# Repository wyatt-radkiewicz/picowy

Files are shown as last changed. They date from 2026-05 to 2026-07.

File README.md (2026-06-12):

# picowy Design Document
This is the design document for the picowy. This is made to be a thin, low power tomagachi like
device for my girlfriend. This design document goes over the basic system configuration and power
requirements. It enumerates every major system component. It does not go into detail about the
coding architecture, that can be found in the firmware directory.

> *eklipsed, rev. 1.0.1*

## Table of Contents
1. [Accelerometer](#accelerometer)
2. [OLED Display](#oled-display)
3. [Microcontroller](#microcontroller)
4. [Touch Panel](#touch-panel)
5. [FTDI Firmware Flasher](#ftdi-firmware-flasher)
6. [Power System](#power-system)
7. [Chassis](#chassis)

## Accelerometer
> Ultra Low-Power 3 Axis Accelerometer
- Manufacturer - *STMicroelectronics*
- Part Number - *LIS2HH12TR*
- Datasheet - [LIS2HH12](hardware/datasheets/accel/lis2hh12.pdf)
- Application Notes - [AN4662](hardware/datasheets/accel/an4662.pdf)

This accelerometer provides real world physics feedback to the simulation.
The SPI interface is used to poll acceleration data per tick of the simulation.
This uses the **Block Data Update (BDU)** feature of the LIS2HH12 to poll
data from the OUT_(X, Y, Z)_(H, L) registers while having old data be overwritten
([AN4662 Section 3.1.3](hardware/datasheets/accel/an4662.pdf#page=14)). Only the newest
data is needed, samples can be skipped since no filtering on the MCU is used.

### Parameters
- $FS=\pm4.0g$ - Measurement range in *g*
([LIS2HH12 Table 3](hardware/datasheets/accel/lis2hh12.pdf#page=10)).
- $So=0.122\frac{mg}{lsb}$ - Sensitivity in OUT registers
([LIS2HH12 Table 3](hardware/datasheets/accel/lis2hh12.pdf#page=10)).
- $ODR=50\mathrm{Hz}$ - Output data rate.
- $I_{ddA}=110\mu\mathrm{A}$ - Current consumption
([LIS2HH12 Table 4](hardware/datasheets/accel/lis2hh12.pdf#page=11)).
- $PX_G=So\times\frac{9800 mm}{s^2 \times lsb}\times\frac{128 px}{20.14 mm}
\times\frac{s}{30 ticks}=253.3\frac{px}{tick^2 \times lsb}$ -
ODR LSB to px per tick^2 conversion rate (@ 30Hz simulation rate).
  - 20.14mm - Screen size
  ([ER-OLED1.12-2 Outline Drawing](hardware/datasheets/oled/er-oled1.12-2.pdf#page=6)).

### Physics Integration
Projecting the accelerometer data onto the screen's X-Y plane is as simple as only converting
the ODR_X_HL and ODR_Y_HL registers into the screen's units and ignoring ODR_Z_HL. Multiply
ODR_X_HL and ODR_Y_HL by $PX_G$ to get the acceleration values used in the physics simulation.

Pictured below is the physical configuration of the accelerometer, where 1 is the first pin.
```
                 ^ z
                 |
               _-|-_
            _-" 1|  "-_
         _-"     |     "-_
       +-_     _-'-_     _-+
       |  "-_-"     "-_-"  |
       +-_-" "-_   _-" "-_-+
      _-" "-_   "+"   _-" "-_
  y <"       "-_ | _-"       "> x
                "+"
```
([LIS2HH12 Section 1.2](hardware/datasheets/accel/lis2hh12.pdf#page=8))

## OLED Display
> 1.12" 128x128 Monochrome White OLED Display
- Manufacturer - *EastRising*
- Part Number - *ER-OLED1.12-2W*
- Datasheet - [ER-OLED1.12-2](hardware/datasheets/oled/er-oled1.12-2.pdf)
- Reference Implementation -
[er-oled1.12-2-interfacing](hardware/datasheets/oled/er-oled1.12-2-interfacing.pdf)
- Controller - [SH1107](hardware/datasheets/oled/sh1107.pdf)
- Connector Datasheet - [ZIF20PIN](hardware/datasheets/oled/er-con20ht-1.pdf)

This OLED has a SPI interface, which can be shared with the internal measurement unit.
The 4-Wire SPI interface is selected, where A0 represents the Data/Command bit. The way that
EastRising designed the display module means that the 12V rail msut be supplied externally.

### Parameters
- $f_{SCK} = \frac{PCLK}{2} = 1.05\mathrm{MHz}$ - SPI interface speed
  - The maximum speed on the OLED's SPI interface is around 4Mhz
  ([SH1107 AC Characteristics](hardware/datasheets/oled/sh1107.pdf#page=52)).
  - The STM32 peripheral (PCLK) clock is the bottleneck. The maximum
  SPI interface speed can be set to $\frac{PCLK}{2}$
  ([RM0377 Section 26.7.1](hardware/datasheets/stm32/rm0377.pdf#page=808)).
- $IPP + IREF = 48\mu \mathrm{A}$ - Current from 12V Rail
([ER-OLED1.12-2 Section 4.3](hardware/datasheets/oled/er-oled1.12-2.pdf#page=9))
- $IDD = 100\mu \mathrm{A}$ - Current from 3.3V Rail
([ER-OLED1.12-2 Section 4.3](hardware/datasheets/oled/er-oled1.12-2.pdf#page=9))

## Microcontroller
> Arm Cortex M0+ Microcontroller 16KB Flash 2KB RAM
- Manufacturer - *STMicroelectronics*
- Part Number - *STM32L011G4U6TR*
- Datasheet - [STM32L011](hardware/datasheets/stm32/stm32l011.pdf)
- Reference Manual - [RM0377](hardware/datasheets/stm32/rm0377.pdf)
- Bootloader Manual - [AN2606](hardware/datasheets/stm32/an2606.pdf)
- USART Bootloader Protocol Manual - [AN3155](hardware/datasheets/stm32/an3155.pdf)
- Programmer's Manual - [PM0223](hardware/datasheets/stm32/pm0223.pdf)

The main program will be a state machine where it runs all functions and then sleeps. This repeats
on a main $30\mathrm{Hz}$ timer.

### Power Mode and Clock Setup
- **Power Mode (VCORE)** - To save power *VCORE Range 3 (1.2V)* will be selected
[RM0377 Section 6.1.4](hardware/datasheets/stm32/rm0377.pdf#page=138).
- **System Clock (SYSCLK)** - SYSCLK will run from the MSI (Multispeed Internal) clock at
$2.1\mathrm{MHz}$ [RM0377 Section 7.2.3](hardware/datasheets/stm32/rm0377.pdf#page=174).
- **Peripherial Clock (PCLK)** - PCLK will be run at the same frequency of $2.1\mathrm{MHz}$.
- **Run Mode** -  When running with no peripherials on except FLASH, and interpolating data from
[STM32L011 Table 22](hardware/datasheets/stm32/stm32l011.pdf#page=53), around $300\mu\mathrm{A}$ is
consumed while running.
- **Sleep Mode** - When in sleep mode running at $65\mathrm{kHz}$ and without FLASH, around
$26.5\mu\mathrm{A}$ is consumed
[STM32L011 Table 26](hardware/datasheets/stm32/stm32l011.pdf#page=56).

### States
#### 1. Wakeup
LPTIM1 is running at $30\mathrm{Hz}$, and wakes up the system.
Driven off of the stable LSI (Low Speed Internal) clock source so that MSI can be changed during
operation. System sets MSI clock back to $2.1\mathrm{MHz}$.
- **Required Peripherials:** PWR, FLASH, LPTIM1
- **Power Consumption:** $300\mu\mathrm{A} + 36.0\mu\mathrm{A} = 336.0\mu\mathrm{A}$
- **Average Runtime $\approx 0.266\mathrm{ms}$**
  - 8 cycles at 65kHz [STM32L011 Section 6.3.5](hardware/datasheets/stm32/stm32l011.pdf#page=62)
  - N cycles at 2.1Mhz (Somewhere in the 100-200 cycles range)

#### 2. Poll Touch Screen
First it runs the *Sense* operation to see if the touch screen is being touched, and only if there
is touch detected does it start up ADC1 and run the *X Pos* and *Y Pos* modes. ADC1 is configured
to run with 1.5 sample time and to run off of the PCLK with 12 bit resolution.
- **Required Peripherials:** PWR, FLASH, LPTIM1, ADC1, GPIO
- **Power Consumption:** $300\mu\mathrm{A} + 61.2\mu\mathrm{A} = 361.2\mu\mathrm{A}$
- **Average Runtime $\approx 0.122\mathrm{ms}$**
  - $1\mu\mathrm{s}$ ADC Power up Time
  [STM32L011 Table 54](hardware/datasheets/stm32/stm32l011.pdf#page=81)
  - $2\times\left(12.5 + 1.5\right)\times\frac{1}{1.05\mathrm{Mhz}}=27\mu\mathrm{s}$
  2 ADC Sample Times [STM32L011 Table 54](hardware/datasheets/stm32/stm32l011.pdf#page=81)
  - N cycles at 2.1Mhz (Somewhere in the 100-200 cycles range)

#### 3. Poll Accelerometer
SPI1 should use $CPOL=1, CPHA=1$ when communicating with the accelerometer. ODR_(X, Y, Z)_(H, L) is
read and converted into *px/tick^2* using the accelerometer's communitcation protocol
[LIS2HH12 Section 6.2](hardware/datasheets/accel/lis2hh12.pdf#page=25). With this protocol,
the ODR_X_L register can be read, and then the rest can follow with DMA1 clocking the SCK signal
for the rest.
- **Required Peripherials:** PWR, FLASH, LPTIM1, SPI1, DMA1, GPIO
- **Power Consumption:** $300\mu\mathrm{A} + 68.6\mu\mathrm{A} = 368.6\mu\mathrm{A}$
- **Average Runtime $\approx 0.291\mathrm{ms}$**
  - 56 SPI cycles
  - N cycles at 2.1Mhz (500 cycles range)

#### 4. Update Simulation
The simulation will use a state machine for the character, and the character will be affected by
the external acceleration seen by the accelerometer, and the touch sensor. It will update the
internal screen bitmap for the next step.
- **Required Peripherials:** PWR, FLASH, LPTIM1
- **Power Consumption:** $300\mu\mathrm{A} + 36.0\mu\mathrm{A} = 336.0\mu\mathrm{A}$
- **Average Runtime $\approx 4.76\mathrm{ms}$**
  - N cycles at 2.1Mhz (10,000 cycles budget)

#### 5. Update Screen
Since the 128x128 screen is too large to fit into 2KB RAM, work arounds are needed. A sprite based
approach with X, Y, W, H pairs and a reference to the bitmap in FLASH works, and with a system that
knows where sprites were previously, full screen rewrites are not needed. Even if a full screen
refresh was needed, it would only take under $18\mathrm{ms}$ when SPI1 runs at full speed
($1.05\mathrm{MHz}$).
- **Required Peripherials:** PWR, FLASH, LPTIM1, SPI1, DMA1, GPIO
- **Power Consumption:** $300\mu\mathrm{A} + 60.3\mu\mathrm{A} = 360.3\mu\mathrm{A}$
- **Average Runtime $\approx 6.19\mathrm{ms}$**
  - 4000 SPI1 cycles (Assuming 1/4 of screen is refreshed)
  - N cycles at 2.1Mhz (5,000 cycles budget)

#### 6. Sleep
This sets the MSI clock to $65\mathrm{kHz}$, disables relevant clock
blocks and peripherals, and exits the LPTIM1 interrupt to go back into sleep mode.
- **Required Peripherials:** PWR, FLASH, LPTIM1
- **Power Consumption:** $26.5\mu\mathrm{A} + 36.0\mu\mathrm{A} = 62.5\mu\mathrm{A}$

### Average Power Consumption
- Time in *Run* mode: $11.7\mathrm{ms}$
- Average current: $360\mu\mathrm{A}\times\frac{11.7}{33.33}+70\mu\mathrm{A}\times
\frac{21.63}{33.33}\approx172\mu\mathrm{A}$

### Debug Connector
> Tag Connect 2030 Solderless Connection
- Manufacturer - *Tag-Connect*
- Part Number - *TC2030*
- Datasheet - [TC2030](hardware/datasheets/conn/tc2030.pdf)

The TC2030 will be connected the STM32's SWCLK, SWDIO, 3.3V, GND, NRST. NRST will be pulled up to
$V_{DD}$. This will use the Serial Wire Debug (SWD) protocol.

## Touch Panel
> 1.44" 4 Wire Resistive Touch Screen
- Manufacturer - *EastRising*
- Part Number - *ER-TP1.44-1*
- Datasheet - [ER-TP1.44-1](hardware/datasheets/touch/er-tp1.44-1.pdf)

The datasheet doesn't contain any info on axis resistance. Design is made around that limitation,
but still the minimum and maximum allowed for the design will be selected for
$300\Omega-600\Omega$. The touch panel circuitry uses no current if the panel is not being touched.

### Diagram
- $R_{AX}$ is the axis resistance, anywhere between the minimum and maximum.
- $R_{TP}$ is current limiting resistor $R_{TP}$.
- *XL*, *YU*, *XR*, *YD* are connected to the STM32's GPIO pins.
```
   Inside TP    . To GPIO
                .
  +--------------------- XL
  |             .
  |      +-------------- YU
  |      |      .
  |     R_AX    .
  |      |      .
  +-R_AX-?-R_AX---R_TP-- XR
         |      .
        R_AX    .
         |      .
         +--------R_TP-- YD
                .
```

### Parameters
- $R_{PD} >= 25k\Omega$ - Minimum pulldown resistor value
([STM32L011 Table 50](hardware/datasheets/stm32/stm32l011.pdf#page=75)).
- $I_{MAX}=2\mathrm{mA}$

### Operation Modes
When sleeping, the touch panel GPIO is all set to Input (*no* pullup/down). This configuration
consumes no current.

#### Touch Sense
| Pin | State |
|-----|---|
| XL  | Out Push-Pull, HI |
| XR  | HZ |
| YU  | In Pull-Down |
| YD  | HZ |
- $I_{TP}=\frac{V_{DD}}{R_{PD}}=0.132\mathrm{mA}$ - GPIO source/sink current (if pressed)
- $V_{TP}=V_{DD}\frac{R_{PD}}{2R_{AX}+R_{IA}+R_{PD}}=3.03\mathrm{V}$ - Touch sense level
  - $R_{IA}$ - Inter-axis touch resistance ($0-1000\Omega$)

#### X/Y Position Reading
| State | XL | XR | YU | YD |
|---|---|---|---|---|
| X Pos | Out Push-Pull, LO | Out Push-Pull, HI | ADC In | HZ |
| Y Pos | ADC In | HZ | Out Push-Pull, LO | Out Push-Pull, HI |

$R_{TP} = 1.4\mathrm{k}\Omega$ - What to use for $R_{TP}$ since only these modes use it
- $R_{TP} > \frac{V_{DD}}{I_{MAX}}-R_{AX}$ - What to select for $R_{TP}$ to keep current low

## FTDI Firmware Flasher
> USB to UART Bridge for Firmware Flashing
- Manufacturer - *FTDI, Future Technology Devices International Ltd*
- Part Number - *FT260Q-T*
- Datasheet - [FT260](hardware/datasheets/ftdi/ft260.pdf)
- Application Notes - [AN394](hardware/datasheets/ftdi/an394.pdf)

This will be used to boot the STM32 into the USART Boot Loader
([AN3155](hardware/datasheets/stm32/an3155.pdf)). Two GPIOs will be used on the FT260, one to
assert NRST on the STM32, and the other to assert the BOOT0 pin on the STM32 to get it into
bootloader mode [AN2606 Table 2](hardware/datasheets/stm32/an2606.pdf#page=34). For this,
nBOOT_SEL must be 0 [RM0377 Section 3.7.8](hardware/datasheets/stm32/rm0377.pdf#page=110).

Support for an external EEPROM configuration chip for the FT260 will be made by making a space
for it on the PCB (need not be populated). This EEPROM chip communicates over $\mathrm{I^2C}$
[FT260 Section 9](hardware/datasheets/ftdi/ft260.pdf#page=44).

### Parameters
- $DCNF1 = 1, DCNF0 = 0$ - Only USART interface is enabled
[FT260 Section 5.1](hardware/datasheets/ftdi/ft260.pdf#page=17)
- $PARITY = EVEN$ [AN3155 Section 3](hardware/datasheets/stm32/an3155.pdf#page=9)
- $Baud\;Rate = 115200$ [AN3155 Section 2.2](hardware/datasheets/stm32/an3155.pdf#page=7)

## Power System
There are 3 distinct power rails, VBUS, 3V3, and 12V. The devices connected to each are:
| RAIL | DEVICES | CURRENT |
|---|---|---|
| VBUS | FT260 | $9.6\mathrm{mA}$ [FT260 Table Section 6.3](hardware/datasheets/ftdi/ft260.pdf#page=29) |
| | Battery Charger | $50\mathrm{mA}$ Set by $EN1=HI,EN2=LO$ [BQ24230 Section 7.5](hardware/datasheets/charger/bq24230.pdf#page=9)  |
| 3V3  | STM32 | $172\mu\mathrm{A}$ [STM32 Average Power Consumption](#microcontroller) |
| | OLED | $100\mu\mathrm{A}$ [OLED Display 3V3 Current](#oled-display) |
| | Accelerometer | $110\mu\mathrm{A}$ [Accelerometer Current](#accelerometer) |
| 12V  | OLED Driver | $32\mu\mathrm{A}$ [OLED Display Driver 12V Current](#oled-display) |

The rated battery charging rate and lack of circuitry needed to negociate USB Battery Charging or
Power Delivery means that the battery charger will have an input current limit of $50\mathrm{mA}$.

With the selected parts, the 3V3 rail draws $1.4\mathrm{mW}$ because of the LDO. The 12V rail draws
$1.2\mathrm{mW}$ due to the $\approx50\%$ efficiency. This means the battery will be sourcing
around $0.7\mathrm{mA}$.

### Battery <TODO>
> 3.7V Thin Lithium Ion Battery Rechargeable
- Manufacturer - *GlobTek, Inc.*
- Part Number - *BL0105F2635161S1PCAT*
- Datasheet - [BL0105F2635161S1PCAT](hardware/datasheets/battery/battery.pdf)

Is very thin $2.8\mathrm{mm}$ thick battery, with thin connector. Stay in the $50\mathrm{mA}$ range
for charging [BL0105F2635161S1PCAT Section 3](hardware/datasheets/battery/battery.pdf#page=3).

#### Male Connector (PCB Side)
- Manufacturer - *Hirose Electric Co Ltd*
- Part Number - *DF65-3P-1.7V(21)*
- Drawing - [DF65-3P-1.7V-21](hardware/datasheets/conn/df65-3p-1.7v-21.pdf)

### Battery Charger
> Battery Charger and Power Path Managment
- Manufacturer - *Texas Instruments*
- Part Number - *BQ24230RGTR*
- Datasheet - [BQ24230](hardware/datasheets/charger/bq24230.pdf)

Using this power path battery charger, it allows instant on from a dead battery. Use custom current
limit though external resistor to give some room for the FT260 to also source current on VBUS and
to not charge the battery at its max all the time.

### Fuel Gauge
> System Side Impeadance Track Fuel Gauge
- Manufacturer - *Texas Instruments*
- Part Number - *BQ27441DRZT-G1A*
- Datasheet - [BQ27441-G1](hardware/datasheets/gauge/bq27441-g1.pdf)
- Technical Reference - [SLUUAC9A](hardware/datasheets/gauge/sluuac9a.pdf)

This is an optional component, and can be added to the $\mathrm{I^2C}$ bus on the STM32 to measure
how much battery is left and how much current the system consumes.

### 3V3 Rail
> Low Noise LDO Voltage Regulator
- Manufacturer - *Texas Instruments*
- Part Number - *TPS7A2033PDBVR*
- Datasheet - [TPS7A20](hardware/datasheets/ldo/tps7a20.pdf)

As shown the in part number, *TPS7A20***33***PDBVR* is a 3.3V low noise, low $I_Q$ LDO for
the 3.3V rail.

### 12V Rail
> Power Step-Up DC-DC Converter
- Manufacturer - *Texas Intruments*
- Part Number - *TPS61040DDCR*
- Datasheet - [TPS61040](hardware/datasheets/boost/tps61040.pdf)

The boost converter suggested by the reference implementation for the OLED. Will have around a
70% efficency a the OLED's advertised current.

## Chassis
### Front View
#### Diagram
```
          __= = = = = = = = = = = = = = =+
       _-"''"-_                          |
     ."        ".                        |
    /   +----+= =\= = = = = = = = =+     |
   /  +--------+= \ = = = = =+     |     |
  ,|  |+------+|= |.= =+     |     |     |
  /   |||    |||   \   |DISP |TPNL |BATT |A
  |   |||    |||   |   |     |     |     |
  \   |+------+|= =/= =+     |     |     |
   \  +--------+= / = = = = =+     |     |
  | "-_ +----+=_-"=|= = = = = = = =+     |
      '"-____-"'= = = = = = = = = = = = =+
  |                |
                    
  |                |
  +----------------+
          B
```
#### Dimensions
| PART | DIMENSION | DESCRIPTION | SIZE (mm) |
|---|---|---|---|
| | A | Device Height | 70 |
| | B | Device Width | 60 |
| DISP [ER-OLED1.12-2 Section 3.1](hardware/datasheets/oled/er-oled1.12-2.pdf#page=6) | H | Display Height | 30.3 |
| | W | Display Width | 27.2 |
| | C | FPC Connector Length (min) | 19.15 |
| TPNL [ER-TP1.44-1](hardware/datasheets/touch/er-tp1.44-1.pdf) | H | Touch Panel Height (max) | 30.7 |
| | W | Touch Panel Width (max) | 34.9 |
| | C | FPC Connector Length (min) | 9.2 |
| BATT [BL0105F2635161S1PCAT Section 8](hardware/datasheets/battery/battery.pdf#page=4) | H | Battery Height (max) | 37 |
| | W | Battery Width (max) | 16.5 |

### Side View
#### Diagram
```
  ________.              .________      
  __A_____|______________|________   }A
  __B___|         C         |_____ = }B= = = =]= = = = =]
        +-+---------------+-+= = = = = = = = =]C        ]H
    H     |_______D_______|          }D                 ]
  _________|      F      |________ = = = = = =]= = = = =]
  __E______|_____________|________ = }E= = = =]F
  __G_____________________________   }G
```

#### Dimensions
| DIMENSION | DESCRIPTION | SIZE (mm) |
|---|---|---|
| A | Acrylic Sheet Thickness (max) | 1.1 |
| B | Acrylic Sheet Thickness (max) | 1.1 |
| C [ER-TP1.44-1](hardware/datasheets/touch/er-tp1.44-1.pdf) | Touch Panel Thickness (max) | 1.2 ($1.1\pm0.1$) |
| D [ER-OLED1.12-2 Section 3.1](hardware/datasheets/oled/er-oled1.12-2.pdf#page=6) | OLED Display Thickness (max) | 1.35 ($1.25\pm0.1$) |
| E | PCB Thickness (max) | 1.7 |
| F  [BL0105F2635161S1PCAT Section 8](hardware/datasheets/battery/battery.pdf#page=4)| Battery Thickness (max) | 2.8 |
| G | Acrylic Sheet Thickness (max) | 1.1 |

- **Full Thickness**
  - $nom = 8\mathrm{mm}$
  - $min = 7.55\mathrm{mm}$
- **PCB Acrylic Clearance** $= 2.5\pm0.35\mathrm{mm}$
- **PCB Touch Panel Clearance** $= 2.45\pm0.2\mathrm{mm}$
- **PCB OLED Clearance** $= 1.2\pm0.1\mathrm{mm}$

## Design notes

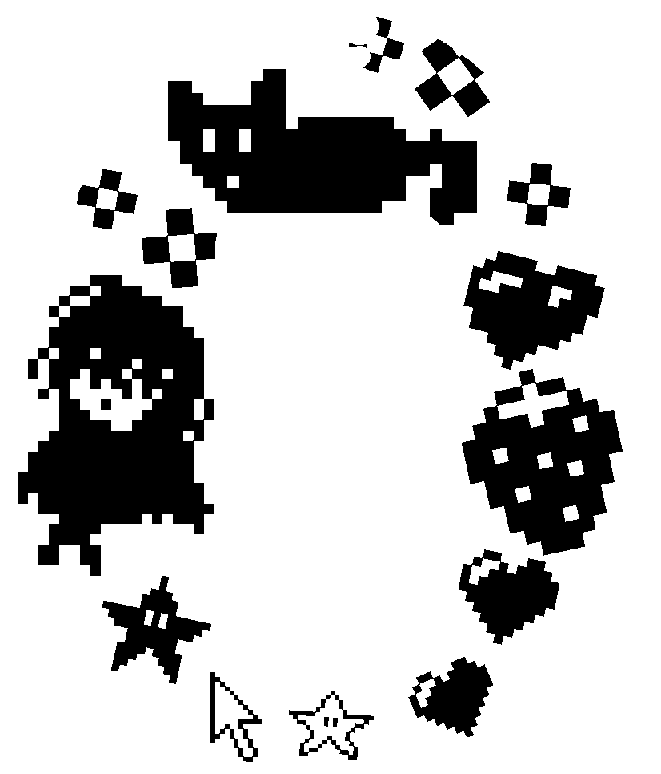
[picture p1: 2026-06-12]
hardware/images/silkscreen-back.png

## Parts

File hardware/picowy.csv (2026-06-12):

Reference | Qty | Value | Manufacturer PN | Manufacturer
BT1 | 1 | Battery | BL0105F2635161S1PCAT | 261635 3.7 V Lithium-Ion Battery Rechargeable (Secondary) 105mAh
C1,C5,C6,C11,C12,C13,C18,C19,C20,C23 | 10 | 100n | C0603C104K3RACTU | KEMET
C2,C3 | 2 | 47p | GCM1885C2A470JA16D | Murata Electronics
C4,C21,C31 | 3 | 10u | GRM188R60J106ME47D | Murata Electronics
C7,C8,C9,C14,C15,C17,C30,C32,C34 | 9 | 4.7u | GRT188C81E475KE13D | Murata Electronics
C10,C16,C22,C25,C26,C27,C28,C29 | 8 | 1u | C0603C105K4RACTU | KEMET
C24 | 1 | 0.47u | GRM188R71E474KA12D | Murata Electronics
C33 | 1 | 4.7p | CC0603CRNPO9BN4R7 | YAGEO
D1 | 1 | STPS0530Z | STPS0530Z | STMicroelectronics
F1 | 1 | VBUS Polyfuse | 0ZCJ0025AF2E | Bel Fuse Inc.
J2 | 1 | Battery Connector | DF65-3P-1.7V(21) | Hirose Electric Co Ltd
J3 | 1 | USB_C_Receptacle_USB2.0_14P | 2130830005 | Molex
L1 | 1 | 6.8u | B82422H1682K000 | TDK
Q1 | 1 | PMOS | BSS84-7-F | Diodes Incorporated
R1,R17,R18 | 3 | 5.1k | RC0603FR-075K1L | YAGEO
R2,R3 | 2 | 1.4k | AC0603FR-071K4L | YAGEO
R4,R5 | 2 | 33 | RC0603FR-0733RL | YAGEO
R6,R7 | 2 | 1k | RC0603FR-071KL | YAGEO
R8,R13,R14,R16,R21,R24,R25,R26 | 8 | 10k | RC0603FR-0710KL | YAGEO
R9 | 1 | 910k | RC0603FR-07910KL | YAGEO
R10 | 1 | 4.7k | RC0402JR-074K7L | YAGEO
R11,R12 | 2 | 2.2k | RC0603FR-072K2L | YAGEO
R15 | 1 | 10m | RL0816T-R010-F | Susumu
R19 | 1 | 17.4k | RT0603DRD0717K4L | YAGEO
R20 | 1 | 30k | RC0603JR-0730KL | YAGEO
R22 | 1 | 1.8M | AC0603FR-071M8L | YAGEO
R23 | 1 | 205k | RC0603FR-07205KL | YAGEO
U1 | 1 | ER-TP1.44-1 | ER-TP1.44-1 | EastRising
U2 | 1 | LIS2HH12 | LIS2HH12TR | STMicroelectronics
U3 | 1 | FT260Q | FT260S-U | FTDI, Future Technology Devices International Ltd
U4 | 1 | ER-OLED1.12-2W | ER-OLED1.12-2W | EastRising
U5 | 1 | AT24CS04-SSHM | AT24CS04-SSHM-T | Microchip Technology
U6 | 1 | STM32L011G4Ux | STM32L011G4U6TR | STMicroelectronics
U7 | 1 | USBLC6-2SC6 | USBLC6-2SC6 | STMicroelectronics
U9 | 1 | TPS7A20xxxDBV | TPS7A2033PDBVR | Texas Instruments
U10 | 1 | BQ24230RGT | BQ24230RGTT | Texas Instruments
U11 | 1 | TPS61040DDC | TPS61040DDCR | Texas Instruments
U12 | 1 | BQ27441-G1 | BQ27441DRZT-G1A | Texas Instruments

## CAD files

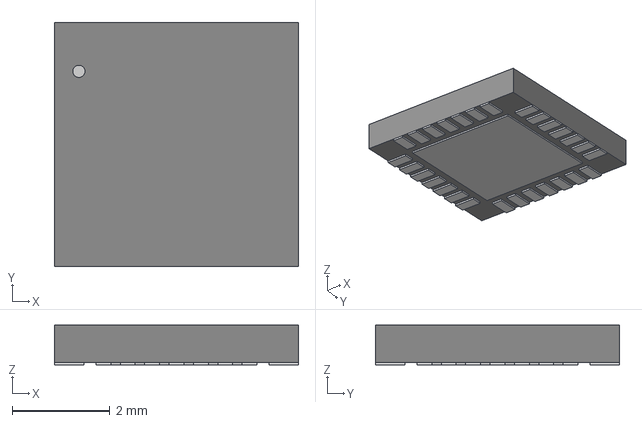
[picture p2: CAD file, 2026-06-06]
hardware/3dmodels/WQFN-28_FTD.step
5.00 x 5.00 x 0.815 mm

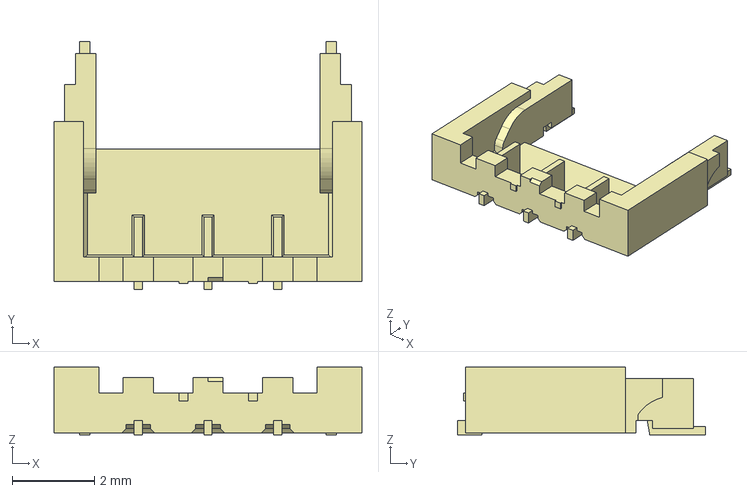
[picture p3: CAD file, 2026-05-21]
hardware/3dmodels/DF65-3P-1.7V.stp
7.50 x 6.05 x 1.65 mm

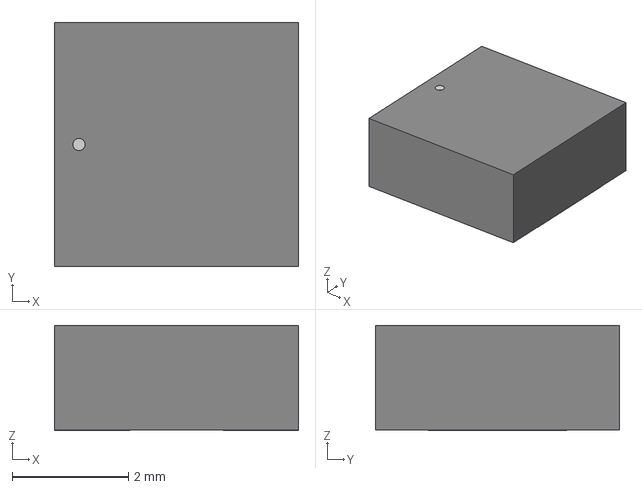
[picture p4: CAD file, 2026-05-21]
hardware/3dmodels/IND_LQH44PN_PR_MUR.step
4.19 x 4.19 x 1.81 mm

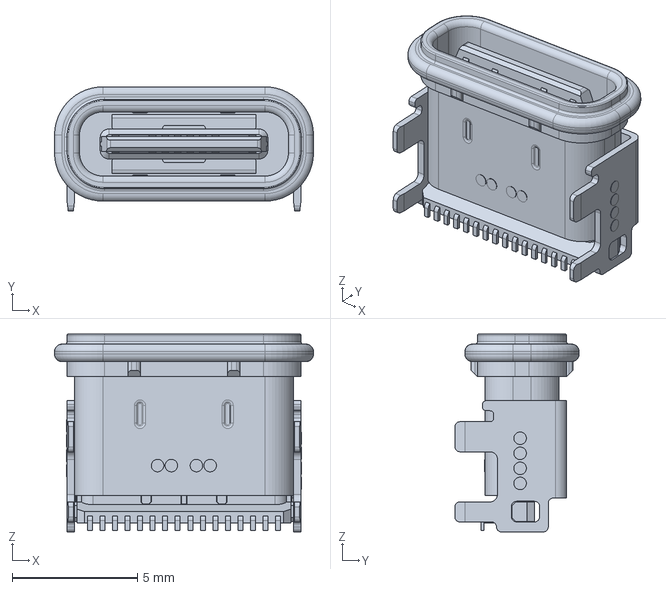
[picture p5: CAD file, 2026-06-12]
hardware/3dmodels/2130830005.stp
10.3 x 4.96 x 7.90 mm

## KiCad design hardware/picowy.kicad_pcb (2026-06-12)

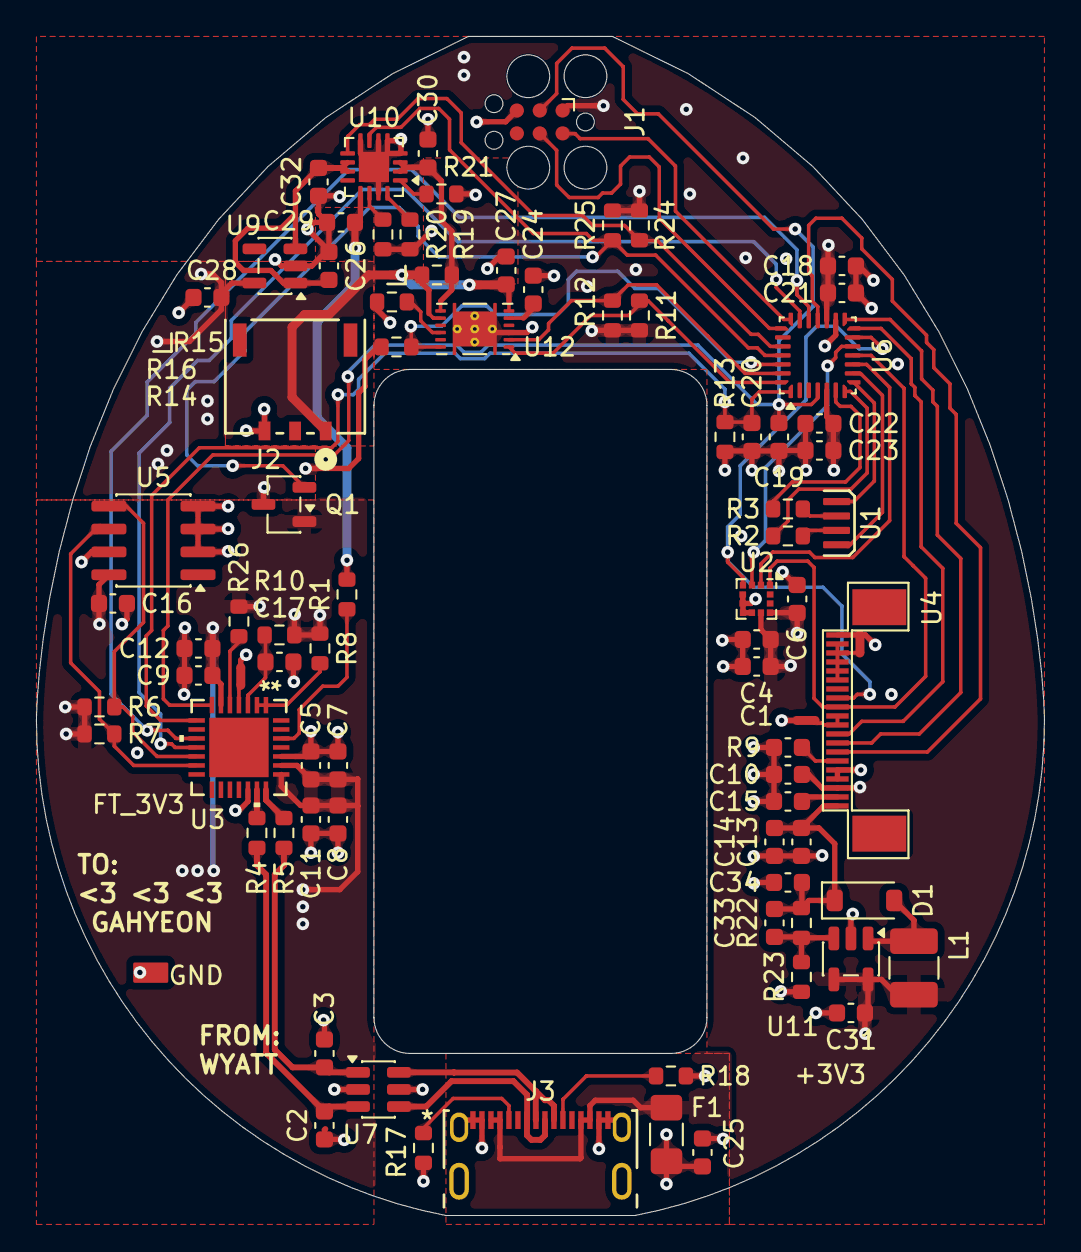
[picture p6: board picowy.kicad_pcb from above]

Board: 4 copper layers, 56.0 x 65.5 mm, 81 parts (0 on the bottom side), 59 nets.

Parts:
C1, C5, C6, C11, C12, C13, C18, C19, C20, C23: 100n; C_0603_1608Metric
C2, C3: 47p; C_0603_1608Metric
C4, C21, C31: 10u; C_0603_1608Metric
C7, C8, C9, C14, C15, C17, C30, C32, C34: 4.7u; C_0603_1608Metric
C10, C16, C22, C25, C26, C27, C28, C29: 1u; C_0603_1608Metric
C24: 0.47u; C_0603_1608Metric
C33: 4.7p; C_0603_1608Metric
D1: STPS0530Z; D_SOD-123
F1: VBUS Polyfuse; Fuse_1206_3216Metric_Pad1.42x1.75mm_HandSolder
J1: Conn_ARM_SWD_TagConnect_TC2030; Tag-Connect_TC2030-IDC-FP_2x03_P1.27mm_Vertical
J2: Battery Connector; CONN_DF65-3P-1.7V21_HIR
J3: USB_C_Receptacle_USB2.0_14P; 2130830005_MOL
L1: 6.8u; L_1210_3225Metric_Pad1.42x2.65mm_HandSolder
NT1: OLED_GPIO_NT; NetTie-2_SMD_Pad0.5mm
NT2: FT_GPIO_GND; NetTie-2_SMD_Pad0.5mm
NT3: OLED_GPIO_NT2; NetTie-2_SMD_Pad0.5mm
Q1: PMOS; SOT-23-3
R1, R17, R18: 5.1k; R_0603_1608Metric
R2, R3: 1.4k; R_0603_1608Metric
R4, R5: 33; R_0603_1608Metric
R6, R7: 1k; R_0603_1608Metric
R8, R13, R14, R16, R21, R24, R25, R26: 10k; R_0603_1608Metric
R9: 910k; C_0603_1608Metric
R10: 4.7k; R_0603_1608Metric
R11, R12: 2.2k; R_0603_1608Metric
R15: 10m; R_0603_1608Metric
R19: 17.4k; R_0603_1608Metric
R20: 30k; R_0603_1608Metric
R22: 1.8M; R_0603_1608Metric
R23: 205k; R_0603_1608Metric
U1: ER-TP1.44-1
U2: LIS2HH12; LGA-12_2x2mm_P0.5mm
U3: FT260Q; WQFN-28_FTD
U4: ER-OLED1.12-2W; ER-CON20HT-1
U5: AT24CS04-SSHM; SOIC-8_3.9x4.9mm_P1.27mm
U6: STM32L011G4Ux; QFN-28_4x4mm_P0.5mm
U7: USBLC6-2SC6; SOT-23-6
U9: TPS7A20xxxDBV; SOT-23-5
U10: BQ24230RGT; VQFN-16-1EP_3x3mm_P0.5mm_EP1.68x1.68mm
U11: TPS61040DDC; SOT-23-5
U12: BQ27441-G1; Texas_S-PDSO-N12

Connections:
+3V3: C1.1, C4.1, C6.1, C10.1, C18.1, C21.1, C22.1, C23.1, C28.1, C31.1, J1.1 (VCC), L1.1, Q1.3 (S), R11.1, R12.2, R14.1, R24.1, R25.1, U2.9 (Vdd), U2.10 (Vdd_IO), U4.3 (VDD), U6.5 (VDDA), U6.17 (VDD), U9.5 (OUT), U11.4 (EN), U11.5 (VIN)
+12V: C13.1, C14.1, C33.1, C34.1, D1.1 (K), R22.1, U4.1 (VPP)
+BATT: C27.1, J2.1, R15.2, U12.6 (BAT), U12.8 (SRP)
/Main System/FT.SCL: R7.2, U3.13 (SDA), U5.6 (SCL)
/Main System/FT.SDA: R6.2, U3.12 (SCL), U5.5 (SDA)
/Main System/FT_D+: R5.1, U3.21 (DP)
/Main System/FT_D-: R4.2, U3.20 (DM)
/Main System/FT_VBUS_DET: R1.1, U3.26 (VBUS_DET)
/Main System/IREF: R9.1, U4.6 (IREF)
/Main System/OLED_GPIO_GND: NT1.2, U4.15 (D3), U4.16 (D4), U4.17 (D5), U4.18 (D6), U4.19 (D7)
/Main System/OLED_GPIO_GND2: NT3.2, U4.10 (~WR), U4.11 (E/~RD)
/Main System/VCOMH: C15.1, U4.2 (VCOMH)
/Main System/XR_TP: R3.1, U1.3 (XR)
/Main System/YD_TP: R2.1, U1.2 (YD)
/Power System/12V_FB: C33.2, R22.2, R23.1, U11.3 (FB)
/Power System/12V_SW: D1.2 (A), L1.2, U11.1 (SW)
/Power System/CHG_ISET: R19.2, U10.16 (ISET)
/Power System/CHG_TMR: R20.2, U10.14 (TMR)
/Power System/CHG_TS: R21.1, U10.1 (TS)
/Power System/GAUGE_BIN: R16.1, U12.10 (BIN)
/Power System/GAUGE_VDD: C24.1, U12.5 (V_{DD})
/Power System/USB_IN_D+: J3.A7 (D-), J3.B7 (D-), U7.6 (I/O1)
/Power System/USB_IN_D-: J3.A6 (D+), J3.B6 (D+), U7.4 (I/O2)
/Power System/USB_VBUS: F1.1, J3.A4 (VBUS), J3.A9 (VBUS), J3.B4 (VBUS), J3.B9 (VBUS)
BATT_IN: C30.1, R15.1, U10.2 (BAT), U10.3 (BAT), U12.7 (SRN)
BOOT0: C20.1, R13.1, U3.8 (DIO1), U6.1 (PB9)
CC1: J3.A5 (CC1), R17.2
CC2: J3.B5 (CC2), R18.2
CHG: R24.2, U6.24 (PB3), U10.9 (CHG)
DC_OLED: U4.9 (A0/DC), U6.14 (PB0)
FT_3V3: C5.1, C7.1, C8.1, C9.1, C11.1, C12.1, C16.1, Q1.1 (D), R6.1, R7.1, R8.1, R10.1, R26.1, U3.6 (VCCIO), U3.22 (VOUT3V3), U3.23 (VCCIN), U5.8 (VCC)
FT_DCNF1: R26.2, U3.5 (DCNF1)
FT_GPIO_HI: R8.2, U3.1 (DEBUGGER), U3.2 (STEST_RSTN)
FT_GPIO_LO: NT2.2, U3.4 (DCNF0)
FT_RESETN: C17.1, R10.2, U3.3 (RESETN)
GND: C1.2, C2.2, C3.2, C4.2, C5.2, C6.2, C7.2, C8.2, C9.2, C10.2, C11.2, C12.2, C13.2, C14.2, C15.2, C16.2, C17.2, C18.2, C19.2, C20.2, C21.2, C22.2, C23.2, C24.2, C25.2, C26.2, C27.2, C28.2, C29.2, C30.2, C31.2, C32.2, C34.2, J1.5 (GND), J2.3, J3.A1 (GND), J3.A12 (GND), J3.B1 (GND), J3.B12 (GND), J3.SH (SHIELD), NT1.1, NT2.1, NT3.1, R9.2, R13.2, R16.2, R17.1, R18.1, R19.1, R20.1, R21.2, R23.2, U2.5 (RES), U2.6 (GND), U2.7 (GND), U2.8 (GND), U3.19 (GND), U3.24 (AGND), U4.4 (BS1), U4.5 (BS2), U4.20 (GND), U5.2 (A1), U5.3 (A2), U5.4 (GND), U5.7 (WP), U6.16 (VSS), U7.2 (GND), U9.2 (GND), U10.4 (CE), U10.5 (EN2), U10.6 (EN1), U10.8 (VSS), U10.15 (TD), U10.17 (VSS), U11.2 (GND), U12.3 (V_{SS}), U12.13 (PAD)
GPOUT: R14.2, U6.26 (PB5), U12.12 (GPOUT)
MCU.MISO: U2.3 (SA0/SDO), U6.12 (SPI1_MISO)
MCU.MOSI: U2.4 (SDA/SDI), U4.13 (D1/MOSI), U6.13 (SPI1_MOSI)
MCU.RX: U3.11 (TXD), U6.20 (USART2_RX)
MCU.SCL: R12.1, U6.27 (I2C1_SCL), U12.2 (SCL)
MCU.SCLK: U2.1 (SCL/SPC), U4.12 (D0/SCLK), U6.11 (SPI1_SCK)
MCU.SDA: R11.2, U6.28 (I2C1_SDA), U12.1 (SDA)
MCU.SWCLK: J1.4 (SWCLK), U6.22 (SYS_SWCLK)
MCU.SWDIO: J1.2 (SWDIO), U6.21 (SYS_SWDIO)
MCU.TX: U3.10 (RXD), U6.19 (USART2_TX)
NRST: C19.1, J1.3 (~RESET), U3.7 (DIO0), U6.4 (NRST)
PGOOD: Q1.2 (G), R25.2, U6.25 (PB4), U10.7 (PGOOD)
USB_D+: C3.1, R5.2, U7.1 (I/O1)
USB_D-: C2.1, R4.1, U7.3 (I/O2)
VBUS: C25.1, C29.1, F1.2, R1.2, U7.5 (VBUS), U10.13 (IN)
VSYS: C26.1, C32.1, U9.1 (IN), U9.3 (EN), U10.10 (OUT), U10.11 (OUT)
XL: U1.1 (XL), U6.9 (PA3)
XR: R3.2, U6.6 (ADC_IN0)
YD: R2.2, U6.7 (ADC_IN1)
YU: U1.4 (YU), U6.8 (PA2)
~CS_ACCEL: U2.2 (~CS), U6.10 (PA4)
~CS_OLED: U4.7 (~CS), U6.18 (PA8)
~RES_OLED: U4.8 (~RES), U6.15 (PB1)

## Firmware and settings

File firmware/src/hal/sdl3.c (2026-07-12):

/// SDL3 Implementation of the HAL
#include <SDL3/SDL.h>
#define SDL_MAIN_USE_CALLBACKS 1
#include <SDL3/SDL_main.h>
#include <math.h>

#include "../app.h"
#include "../hal.h"

// Emulated battery capacity in milliamp hours
#define BATTERY_CAPACITY 105.0f

// SDL3 Application State
// Contains "global" info
struct halstate {
    // SDL3 Application level members
    SDL_Window *window;
    SDL_Renderer *renderer;
    SDL_Time last_tick;
    float loop_duration;

    // Interaction members
    float grab_start_angle, grab_current_angle;
    float mouse_x, mouse_y;
    bool mouse_left;
    bool mouse_right;
    bool mouse_middle;
    int grab_turns;

    // Screen rendering
    SDL_Texture *texture;
    uint8_t screen[SCREEN_WIDTH * SCREEN_HEIGHT / 8];
    float screen_size;

    // Device level members
    float device_angle, grabbed_device_angle;
    float device_angular_vel;
    float battery_capacity;
    float average_milliamps;
    bool is_charging;
};
static struct halstate halstate = {};

//
// Utility functions
//
static inline fixed16_t fixed16_from_float(float x)
{
    if (x <= -128.0f) {
        return -128.0f;
    } else if (x >= 127.0f + 255.0f / 256.0f) {
        return 127.0f + 255.0f / 256.0f;
    }

    return fixed16_init((int8_t)floorf(x), (uint32_t)floorf(x * 255.0f) & 0xff);
}

//
// Start functions
//

SDL_AppResult SDL_AppInit(void **, int argc, char **argv)
{
    // Initialize SDL3
    SDL_SetAppMetadata("picowy emulator", "1.0", "net.eklipsed.picowy");
    if (!SDL_Init(SDL_INIT_VIDEO)) {
        SDL_Log("Couldn't initialize SDL: %s", SDL_GetError());
        return SDL_APP_FAILURE;
    }

    // Create the window and renderer
    if (!SDL_CreateWindowAndRenderer(
            "picowy emulator",
            SCREEN_WIDTH * 5,
            SCREEN_HEIGHT * 5,
            SDL_WINDOW_RESIZABLE,
            &halstate.window,
            &halstate.renderer)) {
        SDL_Log("Couldn't create window and renderer: %s", SDL_GetError());
        return SDL_APP_FAILURE;
    }

    // Get the renderer properties
    SDL_PropertiesID renderer_props = SDL_GetRendererProperties(halstate.renderer);
    if (renderer_props == 0) {
        SDL_Log("Could not retrieve renderer properties: %s", SDL_GetError());
        return SDL_APP_FAILURE;
    }

    // Get the renderer's perffered pixel formats
    const SDL_PixelFormat *renderer_formats = SDL_GetPointerProperty(
        renderer_props,
        SDL_PROP_RENDERER_TEXTURE_FORMATS_POINTER,
        nullptr);
    if (!renderer_formats) {
        SDL_Log("Could not query renderer pixel format: %s", SDL_GetError());
        return SDL_APP_FAILURE;
    }

    // Get the first one, or the one that the window supports
    SDL_PixelFormat renderer_format = renderer_formats[0];
    if (renderer_format == SDL_PIXELFORMAT_UNKNOWN
        && (renderer_format = SDL_GetWindowPixelFormat(halstate.window))
            == SDL_PIXELFORMAT_UNKNOWN) {
        SDL_Log("Could not query window pixel format: %s", SDL_GetError());
        return SDL_APP_FAILURE;
    }

    // Create a texture to stream the screen bitmap to
    if (!(halstate.texture = SDL_CreateTexture(
              halstate.renderer,
              renderer_format,
              SDL_TEXTUREACCESS_STREAMING,
              SCREEN_WIDTH,
              SCREEN_HEIGHT))) {
        SDL_Log("Could not create screen texture: %s", SDL_GetError());
        return SDL_APP_FAILURE;
    }
    SDL_SetTextureScaleMode(halstate.texture, SDL_SCALEMODE_NEAREST);

    // Initialize other members of the halstate
    SDL_GetCurrentTime(&halstate.last_tick);
    halstate.battery_capacity = BATTERY_CAPACITY;
    halstate.loop_duration = 1.0f / (float)HAL_HZ;

    // Initialize the app and continue
    app_init();
    return SDL_APP_CONTINUE;
}

SDL_AppResult SDL_AppEvent(void *, SDL_Event *event)
{
    switch (event->type) {
    // Quit the emulator if user requests it
    case SDL_EVENT_QUIT:
        return SDL_APP_SUCCESS;
    }
    return SDL_APP_CONTINUE;
}

SDL_AppResult SDL_AppIterate(void *)
{
    // Get current window size
    int window_w, window_h;
    SDL_GetWindowSize(halstate.window, &window_w, &window_h);
    float window_centerx = (float)window_w / 2.0f;
    float window_centery = (float)window_h / 2.0f;

    // Get elapsed time
    SDL_Time current_tick;
    SDL_GetCurrentTime(&current_tick);
    float elapsed_time = (float)(current_tick - halstate.last_tick) / 1e9f;
    halstate.last_tick = current_tick;
    if (elapsed_time <= 0.0f) {
        elapsed_time = 1e-9f;
    } else if (elapsed_time >= 0.1f) {
        elapsed_time = 0.1f;
    }

    // Get the new mouse state
    float mouse_x, mouse_y;
    SDL_MouseButtonFlags mouse_buttons = SDL_GetMouseState(&mouse_x, &mouse_y);
    mouse_x -= window_centerx;
    mouse_y -= window_centery;
    halstate.mouse_left = mouse_buttons & SDL_BUTTON_LMASK;

    // Rotate the device
    if (mouse_buttons & SDL_BUTTON_RMASK) {
        // Apply turns
        if (mouse_y < 0.0f) {
            if (mouse_x <= 0.0f && halstate.mouse_x > 0.0f) {
                halstate.grab_turns += 1;
            } else if (mouse_x >= 0.0f && halstate.mouse_x < 0.0f) {
                halstate.grab_turns -= 1;
            }
        }

        // Update the current grabbing angle
        halstate.grab_current_angle = atan2f(mouse_x, mouse_y)
            + (float)halstate.grab_turns * M_PI * 2.0f;

        // Right mouse button was just pressed
        if (!halstate.mouse_right) {
            halstate.grab_start_angle = halstate.grab_current_angle;
            halstate.grabbed_device_angle = halstate.device_angle;
        }

        // Drag the current device angle to the angle we want it to be at
        float mouse_grab_delta = halstate.grab_current_angle - halstate.grab_start_angle;
        float wanted_device_angle = halstate.grabbed_device_angle + mouse_grab_delta;
        halstate.device_angular_vel = (wanted_device_angle - halstate.device_angle) * 0.9f;
        halstate.device_angular_vel /= 0.1f;
    } else {
        halstate.grab_turns = 0;
    }
    halstate.mouse_right = mouse_buttons & SDL_BUTTON_RMASK;
    halstate.mouse_x = mouse_x;
    halstate.mouse_y = mouse_y;

    // Apply the angular momentum to the device
    halstate.device_angle += halstate.device_angular_vel * elapsed_time;
    halstate.device_angular_vel *= expf(elapsed_time * -6.0f);
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

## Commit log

2026-05-01 Created README.md
    [picowy.kicad_pcb, picowy.kicad_sch]
2026-05-12 Main system done, debug system and power system next
2026-05-14 Only 3V3 and 12V Rail left in hardware design doc
2026-05-15 Added accelerometer schematic
    [picowy.kicad_sch, power_system.kicad_sch]
2026-05-21 finished schematic
    [124018612112A.STEP, DF65-3P-1.7V.stp, IND_LQH44PN_PR_MUR.step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]
2026-05-23 fixed power side
    [picowy.kicad_pcb, picowy.kicad_sch, power_system.kicad_sch]
2026-06-06 Restarting routing
    [WQFN-28_FTD.step, picowy.kicad_pcb, picowy.kicad_sch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]
2026-06-12 Finished Board for Fabrication
    [124018612112A.STEP, 2130830005.stp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]
2026-07-03 Making STM32 library
